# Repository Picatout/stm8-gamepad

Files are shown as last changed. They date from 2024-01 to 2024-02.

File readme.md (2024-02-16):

# stm8 gamepad

Console jeu rétro réalisée sur carte NUCLEO-8S207K8. 

## Caractéristiques

* Sortie vidéo composite NTSC 
* Affichage 200x192 pixels noir & blanc.
* pad de 6 boutons croix et boutons A, B.
* Petit haut-parleur pour tonalités et bruit blanc.

## Documentation

[api.md](api.md)

[docs/api.pdf](docs/api.pdf)

## Prototypes

J'ai fabriqué 2 prototypes.  Le premier est réalisé avec un stm8s207k8 et le 2ième avec une carte NUCLEO-8S207K8. Pour ceux qui n'ont pas de programmeurs ST-LINK la 2ième option s'impose.

### Prototype 1

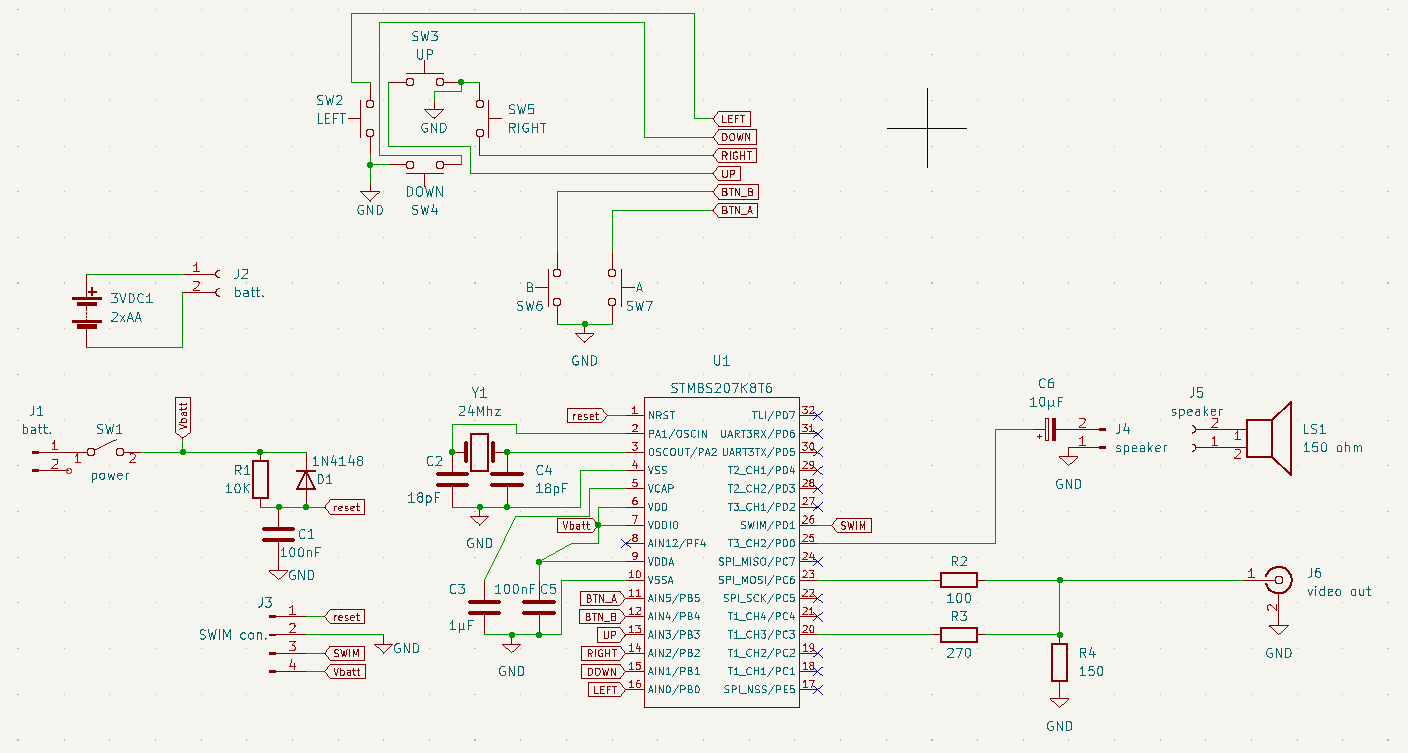
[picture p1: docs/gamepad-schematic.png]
schématique prototype 1


montage prototype 1

L'ensemble tient sur une seule carte.

### Prototype 2

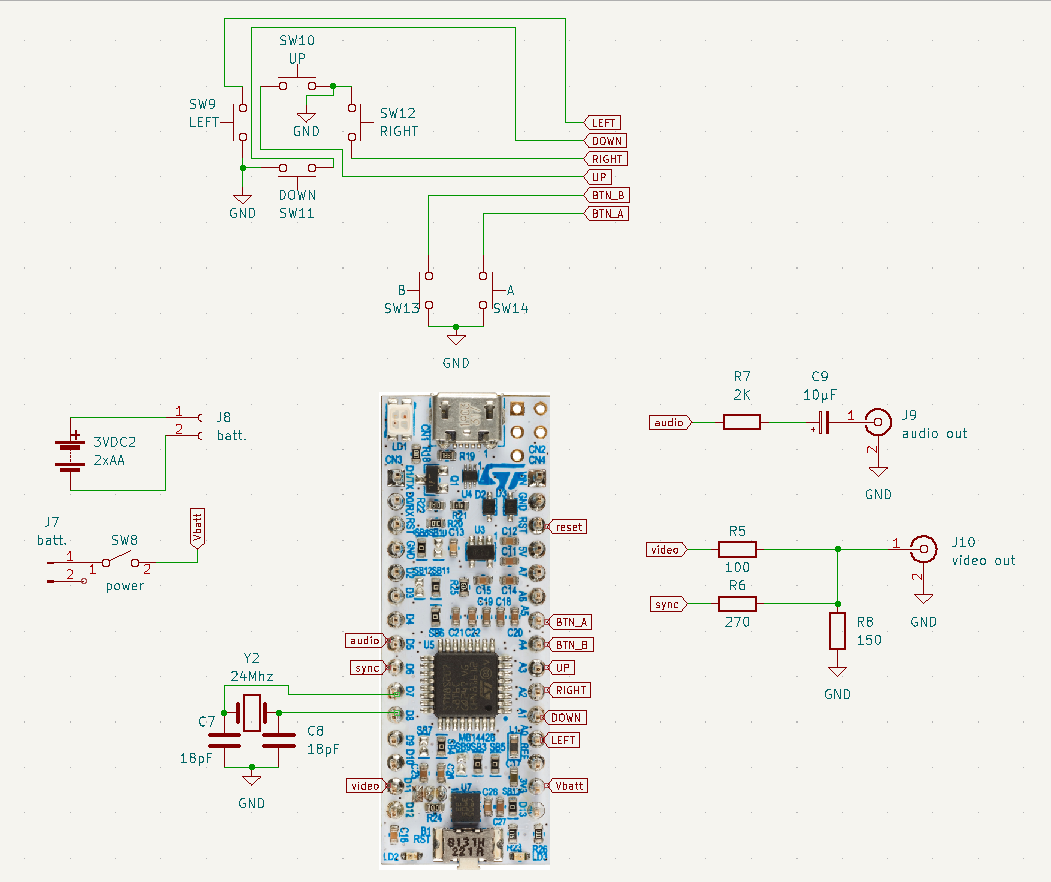
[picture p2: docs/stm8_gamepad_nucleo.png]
schématique prototype 2


montage prototype 2 assemblé

montage prototype 2 désassemblé

La carte des boutons est enfichée par dessus la carte du circuit principal. De plus il n'y a pas de haut-parleur installé mais plutôt une sortie phono RCA (blanc) pour l'audio.

## Mise à jours

### 2024-02-16, V1.5R0

J'ai effectué 2 modficications au circuit ainsi que les modifications logicielles requises par ces changements.

1. La résistance de **150 ohm** à la sortie vidéo a été remplacée par une résistance de **100 ohm** pour augmenter la luminosité.
1. Le cristal de **16Mhz** a été remplacé par un cristal de **24Mhz**. Ceci a 3 conséquences.
    * le rapport largeur/hauteur de l'image qui étirait les pixels en largeur est maintenant très proche ce l'unité donc la routine **circle** n'a plus besoin de faire une correction et le bitmap du chien qui s'affiche au démarrage a un aspect plus normal.
    * l'image n'occupe plus que les 2/3 de la largeur de l'écran. Ça implique que du temps est libéré (environ 17µSec/scan line) donnant plus temps d'exécution au cpu pour les autres tâche.
    * La vitesse d'exécution est augmenter.

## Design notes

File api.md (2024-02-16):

<!--
;;
; Copyright Jacques Deschênes 2023,2024  
; This file is part of stm8-gamepad
;
;     stm8-gamepadis free software: you can redistribute it and/or modify
;     it under the terms of the GNU General Public License as published by
;     the Free Software Foundation, either version 3 of the License, or
;     (at your option) any later version.
;
;     stm8-gamepadis distributed in the hope that it will be useful,
;     but WITHOUT ANY WARRANTY; without even the implied warranty of
;     MERCHANTABILITY or FITNESS FOR A PARTICULAR PURPOSE.  See the
;     GNU General Public License for more details.
;
;     You should have received a copy of the GNU General Public License
;     along with ntsc_tuto.  If not, see <http://www.gnu.org/licenses/>.
;;
-->
# interface d'application 

Ce document décrit les fonctions à utiliser pour programmer des applications pour la console STM8-GAMEPAD.

Les applications doivent-être écrites en assembleur car les paramètres des fonctions sont passés dans les registres **A**,**X** et **Y**  et non sur la pile comme le langage **C** le fait.

Il y a toujours moyen d'écrire les applications en **C** mais en utilisant l'assembleur inline pour charger les registres et faire l'appel vers la sous-routine.

## NOTES 

1. Les valeurs d'intervalles sont indiqué de la façon suivante **[début..fin[ | ]**  
    * Si la valeur *fin* est suivie de **[** ça signifie que cette valeur est exclue de l'intervalle.
    * Si la valeur *fin* est suivie de **]** ça signifie que cette valeur est incluse dans l'intervalle.

2.  **HRES**  Résolution horizontale de l'affichage. 

3.  **VRES** Résolution verticale de l'affichage. 

4. **cx** varible octet contenant la coordonnée x du curseur texte. **[0..CHAR_PER_LINE[**.

5. **cy** variable octet contenant la coordonnée y du curseur texte. **[0..LINE_PER_SCREEN[**.

6. **CHAR_PER_LINE** Nombre de caractères affichable par ligne. 

7. **LINE_PER_SCREEN** Nombre de lignes par écran. 

8. Les variables **cx** et **cy** peuvent-être modifiées par le programme pour positionner le curseur texte. La fonction **tv_cls** les initialisent à **0**.

9. L'espace réservé pour les variables d'application est dans l'intervalle **[4..KERNEL_VAR_ORG[**. Présentement **KERNEL_VAR_ORG=0x60**. Vérifiez cette valeur dans le fichier [hardware_init.asm](hardware_init.asm).  
Les applications définissent leur variables dans le segment **G_DATA** comme suit
```
    .area G_DATA (ABS)
    .org 4 
score: .blkw 1 ; game score 
speed: .blkb 1 ; snake speed delay
chrono: .blkb 1 ; chronometer delay 
max_score: .blkw 1 ; maximum score 
game_flags: .blkb 1 ; game boolean flags 
snake_len: .blkb 1 ; snake length 
snake_dir: .blkb 1 ; head direction 
food_coord: .blkw 1 ; food coordinates
snake_body: .blkw 32 ;  snake rings coords 
```

10. Lorsqu'une application est ajoutée au système ses nom et adresse doivent-être ajoutés au système de menu dans le fichier [app.asm](app.asm). Cette liste doit se terminée par une valeur nulle.
```
prog_list: ; liste des applications disponibles.
.asciz "SNAKE" ; nom qui apparaît dans le menu
.word snake ; nom de la fonction qui lance l'application.
; 2ième application 
.asciz "FALL" 
.word fall
; 3ième application
.asciz "QUICK BROWN FOX"  
.word quick
; fin de la liste
.word 0  
```
Le menu supporte un maximum de 24 applications. C'est le nombre de lignes texte de l'affichage et cette valeur ne devrait pas varier.

11. La mémoire étendue du stm8s207k8 de **32Ko** **[0x10000..0x17FFF]** n'est pas utilisée par le système mais une application peut l'utiliser pour sauvegarder des données persistantes. l'EEPROM de **2Ko** **[0x4000..0x47FF]** peut aussi être utilisée à cet effet.

<hr>

## <a id="index">index</a>

* <a href="#son">SON</a>
* <a href="#keypad">KEYPAD</a>
* <a href="#affichage">AFFICHAGE</a>
* <a href="#divers">DIVERS</a>

##  <a id="son">SON</a> 

* **beep** Cette sous-routine n'accepte aucun paramètre. Elle génère un son de 1000 Hertz pour une durée de 8/60ième de seconde (i.e. ~133msec).
<hr>

* **tone** génère une tonalité de fréquence spécifiée dans le registre **X** et de durée en 60ième de seconde spécifiée dans le registre **A**.
    * **A**   durée du son en 60ìème de seconde. 
    * **X**   fréquence en hertz.
<hr>

* **tune**  Joue une séquence de notes. Le registre **Y** indique l'adresse de la séquence. 
    * **Y**  adresse de la mélodie. Il s'agit d'une liste formée de la fréquence suivit de la durée. La liste doit se terminer par {0,0}. La macro **_note f,d** facilite la constuction de cette liste. 
    * une fréquence nulle indique une pause.

```
	.macro _note  f,d 
	.word f 
	.byte d 
	.endm 

play_scale: 
    ldw y,#gamme 
    call tune 
    ret 

gamme: 
    _note 523,10  ; do 
    _note 554,10  ; do#
    _note 587,10  ; ré 
    _note 622,10  ; ré#
    _note 659,10  ; mi 
    _note 698,10  ; fa 
    _note 740,10  ; fa# 
    _note 784,10  ; sol
    _note 831,10  ; sol#
    _note 880,10  ; la 
    _note 932,10  ; la# 
    _note 988,10  ; si 
    _note 0,0     ; end  
```
<hr>

* **noise**  Produit un bruit blanc d'une durée indiquée par le paramètre passé dans **A**.
    * **A** Durée en 60ième de seconde.

<a href="#index">index</a>

##  <a id="keypad">KEYPAD</a> 

* **keypad_input**  Retourne l'état des 6 boutons dans le registre **A**. Cette lecture n'est pas filtrée pour les rebonds des commutateurs. Les constantes suivantes sont définies pour identifier les boutons.
    * **BTN_LEFT=1**
    * **BTN_DOWN=2**
    * **BTN_RIGHT=4**
    * **BTN_UP=8** 
    * **BTN_B=16**
    * **BTN_A=32**

<hr>

* **read_keypad** Lecture du keypad avec filtrage antirebond. L'état des boutons est retournée dans le registre **A**. Exemple d'utilisation:
```
;--------------------------
; read keypad 
; LEFT turn left 
; RIGHT turn right 
; UP increase speed 
; DOWN decreas speed 
;--------------------------
    KPAD=1
user_input:
    push #0 
    call read_keypad
    jreq 8$ 
    ld (KPAD,sp),a  
    ld a,#BTN_LEFT 
    and a,(KPAD,sp)
    jreq 2$ 
    call rotate_head
    jra 6$
2$: ld a,#BTN_RIGHT 
    and a,(KPAD,sp)
    jreq 3$ 
    call rotate_head
    jra 6$ 
3$:
    ld a,#BTN_UP 
    and a,(KPAD,sp)
    jreq 4$
    ld a,#MIN_SPEED 
    cp a,speed 
    jreq 6$  
    _decz speed
    call prt_info 
    jra 6$ 
4$: ld a,#BTN_DOWN 
    and a,(KPAD,sp)
    jreq 6$
    ld a,#MAX_SPEED 
    cp a,speed 
    jreq 6$
    _incz speed
    call prt_info  
6$:
    ldw x,#10
    call wait_key_release
8$:
    _drop 1 
    ret 
```
<hr>

* **wait_key** Attend qu'un bouton soit enfoncé et retourne l'état dans le registre **A**. 
<hr>

* **wait _key_release** Attend que tous les boutons soient relâchés.  Un délais d'expiration de l'attente doit-être founis dans **X**.
    * **X**  délais d'expiration de l'attente en 60ième de seconde.

<a href="#index">index</a>

##  <a id="affichage">AFFICHAGE</a> 

* **tv_cls**  Efface l'affichage au complet.
<hr>

* **get_pixel** retourne l'état du pixel dans le registre **A**.
    * **XL** coordonnée X du pixel [0..HRES[.
    * **XH** coordonnée Y du pixel [0..VRES[. 

<hr>

* **put_pixel** met le pixel dans l'état déterminé par le contenu du registre **A**
    * **A**  **0** -&gt; éteint le pixel. Autre allume le pixel.
    * **XL** coordonnée X du pixel [0..HRES[.
    * **XH** coordonnée Y du pixel [0..VRES[. 

<hr>

* **set_pixel** Allume un pixel. Les paramètres sont passés dans le registre **X**.
    * **XL** coordonnée X du pixel [0..HRES[.
    * **XH** coordonnée Y du pixel [0..VRES[. 
<hr>

* **reset_pixel** Éteint un pixel. Les paramètres sont passés dans le registre **X**.
    * **XL** coordonnée X du pixel {0..HRES-1}.
    * **XH** coordonnée Y du pixel {0..VRES-1}.
<hr>

* **invert_pixel** Inverse l'état du pixel. Les paramètres sont passés dans le registre **X**.
    * **XL** coordonnée X du pixel {0..HRES-1}.
    * **XH** coordonnée Y du pixel {0..VRES-1}.
<hr>

* **clr_text_line** Efface une ligne de texte.
    * **A**  numéro de la ligne à effacer {0..23}.

<hr>

* **scroll_text_up**  Décale l'affichage texte vers le haut d'une ligne et efface la dernière ligne.
<hr>

* **crlf**  Carriage return line feed. Renvoie le curseur texte au début de la ligne suivante.
<hr>

* **cursor_right** Déplace le curseur texte vers la droite d'un caractère.
<hr>

* **tv_putc** Affiche le caractère qui est dans le registre **A** à la position 
courante du curseur texte. Avance le curseur à la position suivante.
    * **A**  caractère à affiché.
<hr>

* **tv_puts** Affiche une chaîne ce caractères ASCII zéro terminée à la position actuelle du curseur. Àprès l'impression **Y** pointe sur le zéro terminal de la chaîne.
    * **Y** adresse de la chaîne ASCIZ. 
<hr>

* **center_align**  affiche une ligne de texte centrée horizontalement. Àprès l'impression **Y** pointe sur le zéro terminal de la chaîne. 
    * **Y** adresse de la chaîne ASCIZ.

<hr>

* **put_uint16**  Affiche à la position du curseur la valeur entière non signée contenue dans le registre **X**.
    * **X** Entier à afficher.
<hr>

* **roll_up** déroule l'affichage vers le haut jusqu'à ce qu'il soit vide ou qu'une touche du kpad soit enfoncée.
    * **A**  délais contrôlant la vitesse de déroulement. Le délais est en 60ième de secondes.

<hr>

* **line**  Trace une ligne droite entre les coordonnées **{x0,y0}** et **{x1,y1}** excluant ce dernier point.
    * **XL** coordonnée **x0** [0..HRES[
    * **XH** coordonnée **y0** [0..VRES[
    * **YL** coordonnée **x1**  [0..HRES[
    * **YH** coordonnée **y1** [0..VRES[
<hr>

* **rectangle** Dessine un rectangle dont les coordonnées des coins supérieur gauche et inférieur droit sont données.
    * **X**  coordonnées coin supérieur gauche,
        * **XH**  ycoord y0 [0..VRES[   
        * **XL**  xcoord x0 [0..HRES[
    * **Y** coordonnées coin inférieur droit,    
        * **YH**  ycoord y1 [0..VRES[ 
        * **YL**  xcoord x1 [0..HRES[

<hr>

* **circle**  Dessine un cercle avec correction *ASPECT_RATIO* 
    * **A**   rayon 
    * **XL**  xcoord 
    * **XH**  ycooord 

Les constantes pour corriger l'*ASPTECT RATIO* sont dans le fichier [config.inc](config.inc)

* **ASPECT_MUL=59**
* **ASPECT_DIV=36** 

Ces valeurs peuvent dépendre du moniteur utilisé.

<hr>

* **put_sprite** Affiche un petit graphique d'au maximum 8 pixels en largeur et un maximum de **VRES** pixels en hauteur. Chaque rangé du sprite est représenté par un seul octet et le sprite comprend autant d'octets que sa hauteur. La fonction logique **XOR** est utilisée pour afficher les sprites. Cette méthode permet de détecter automatiquement les collisions. La fonction retourne une valeur dand **A** et ajuste le drapeau **Z** en fonction de cette valeur.

Entrées:
* **A** hauteur du sprite 
* **XL** coordonnée x à gauche du sprite.
* **XH** coordonnnée y haut du sprite.
* **Y**  adresse du sprite 

Sorties:
* **A**  différent de zéro s'il y a eu collision 
* **Z**  **0** s'il y a eu collision.
<hr>

* **scroll_up**  Glisse les rangées de l'intervalle [de...jusqu'à[ vers le haut d'une rangée et efface les pixels de la dernière rangée.
    * **XL** *de* 
    * **XH** *jusqu'à* (exclue) 
<hr>

* **scroll_down** Glisse les rangées de l'intervalle [de...jusqu'à[ vers le bas d'une rangée et efface les pixels de la première rangée.
    * **XL** *de* 
    * **XH** *jusqu'à* (exclue)
<hr>

* **scroll_left** Glisse vers la gauche de 4 pixels l'intervalle de rangées [de...jusqu'à[ et efface les pixels à droite de l'écran.
    * **XL** *de* 
    * **XH** *jusqu'à* (exclue)
<hr>

* **scroll_right** Glisse vers la droite de 4 pixels l'intervalle de rangées [de...jusqu'à[ et efface les pixels à gauche de l'écran.
    * **XL** *de* 
    * **XH** *jusqu'à* (exclue)
<hr>

<a href="#index">index</a>

## <a id="divers">DIVERS</a>

* **pause**   Suspend l'exécution pour une durée déterminée par la valeur passée dans **A**.
    * **A** durée de la pause en 60ième de seconde.

<a href="#index">index</a>

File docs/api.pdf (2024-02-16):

api.md | 2024-02-16

# interface d'application

Ce document décrit les fonctions à utiliser pour programmer des applications pour la console STM8-GAMEPAD.

Les applications doivent-être écrites en assembleur car les paramètres des fonctions sont passés dans les registres A,X et Y et non sur la pile comme le langage C le fait.

Il y a toujours moyen d'écrire les applications en C mais en utilisant l'assembleur inline pour charger les registres et faire l'appel vers la sous-routine.

## NOTES

1. Les valeurs d'intervalles sont indiqué de la façon suivante [début..fin[ | ]

Si la valeur fin est suivie de [ ça signifie que cette valeur est exclue de l'intervalle. Si la valeur fin est suivie de ] ça signifie que cette valeur est incluse dans l'intervalle.

2. HRES Résolution horizontale de l'affichage.
3. VRES Résolution verticale de l'affichage.
4. cx varible octet contenant la coordonnée x du curseur texte. [0..CHAR_PER_LINE[.
5. cy variable octet contenant la coordonnée y du curseur texte. [0..LINE_PER_SCREEN[.
6. CHAR_PER_LINE Nombre de caractères affichable par ligne.
7. LINE_PER_SCREEN Nombre de lignes par écran.
8. Les variables cx et cy peuvent-être modifiées par le programme pour positionner le curseur texte. La fonction tv_cls les initialisent à 0.
9. L'espace réservé pour les variables d'application est dans l'intervalle [4..KERNEL_VAR_ORG[. Présentement KERNEL_VAR_ORG=0x60. Vérifiez cette valeur dans le fichier hardware_init.asm. Les applications définissent leur variables dans le segment G_DATA comme suit

.area G_DATA (ABS)
.org 4
score: .blkw 1 ; game score
speed: .blkb 1 ; snake speed delay chrono: .blkb 1 ; chronometer delay max_score: .blkw 1 ; maximum score game_flags: .blkb 1 ; game boolean flags snake_len: .blkb 1 ; snake length snake_dir: .blkb 1 ; head direction food_coord: .blkw 1 ; food coordinates snake_body: .blkw 32 ; snake rings coords

10. Lorsqu'une application est ajoutée au système ses nom et adresse doivent-être ajoutés au système de menu dans le fichier app.asm. Cette liste doit se terminée par une valeur nulle.

prog_list: ; liste des applications disponibles.
.asciz "SNAKE" ; nom qui apparaît dans le menu
.word snake ; nom de la fonction qui lance l'application. ; 2ième application
.asciz "FALL"
.word fall
; 3ième application
.asciz "QUICK BROWN FOX"
.word quick
; fin de la liste
.word 0

Le menu supporte un maximum de 24 applications. C'est le nombre de lignes texte de l'affichage et cette valeur ne devrait pas varier.

11. La mémoire étendue du stm8s207k8 de 32Ko [0x10000..0x17FFF] n'est pas utilisée par le système mais une application peut l'utiliser pour sauvegarder des données persistantes. l'EEPROM de 2Ko [0x4000..0x47FF] peut aussi être utilisée à cet effet.

## index

SON
KEYPAD
AFFICHAGE
DIVERS

## SON

beep Cette sous-routine n'accepte aucun paramètre. Elle génère un son de 1000 Hertz pour une durée de 8/60ième de seconde (i.e. ~133msec).

tone génère une tonalité de fréquence spécifiée dans le registre X et de durée en 60ième de seconde spécifiée dans le registre A.
A durée du son en 60ìème de seconde.
X fréquence en hertz.

tune Joue une séquence de notes. Le registre Y indique l'adresse de la séquence.
Y adresse de la mélodie. Il s'agit d'une liste formée de la fréquence suivit de la durée. La liste doit se terminer par {0,0}. La macro _note f,d facilite la constuction de cette liste.

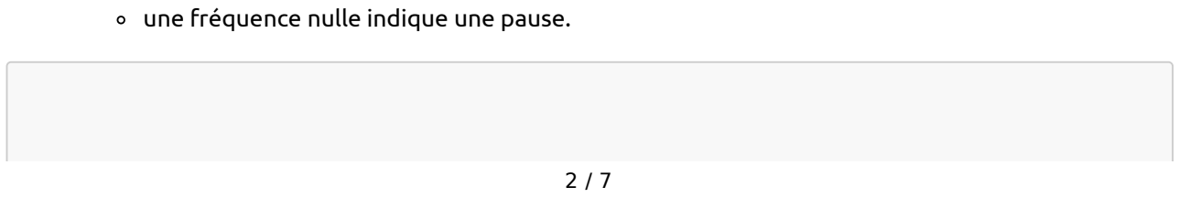
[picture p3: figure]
une fréquence nulle indique une pause.

.macro _note f,d
.word f
.byte d
.endm

play_scale:
ldw y,#gamme
call tune
ret

gamme:
_note 523,10 ; do
_note 554,10 ; do#
_note 587,10 ; ré
_note 622,10 ; ré#
_note 659,10 ; mi
_note 698,10 ; fa
_note 740,10 ; fa#
_note 784,10 ; sol
_note 831,10 ; sol#
_note 880,10 ; la
_note 932,10 ; la#
_note 988,10 ; si
_note 0,0 ; end

noise Produit un bruit blanc d'une durée indiquée par le paramètre passé dans A. A Durée en 60ième de seconde.

index

## KEYPAD

keypad_input Retourne l'état des 6 boutons dans le registre A. Cette lecture n'est pas filtrée pour les rebonds des commutateurs. Les constantes suivantes sont définies pour identifier les boutons. BTN_LEFT=1
BTN_DOWN=2
BTN_RIGHT=4
BTN_UP=8
BTN_B=16
BTN_A=32

read_keypad Lecture du keypad avec filtrage antirebond. L'état des boutons est retournée dans le

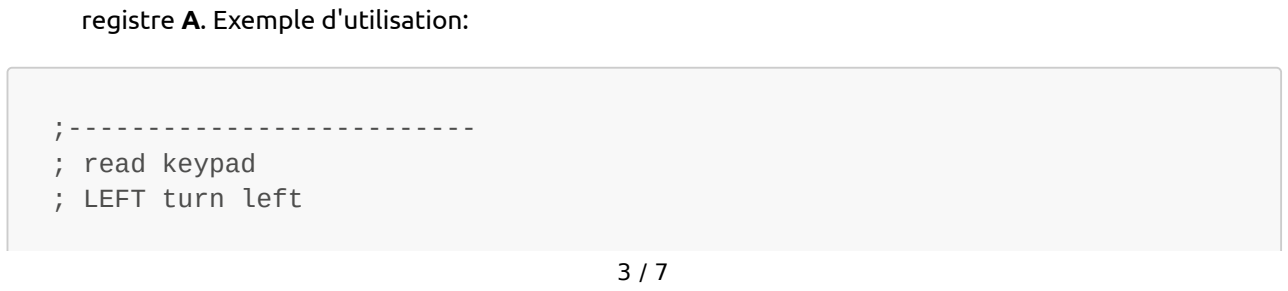
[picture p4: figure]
registre A. Exemple d'utilisation:; ;-------------------------- ; read keypad ; LEFT turn left

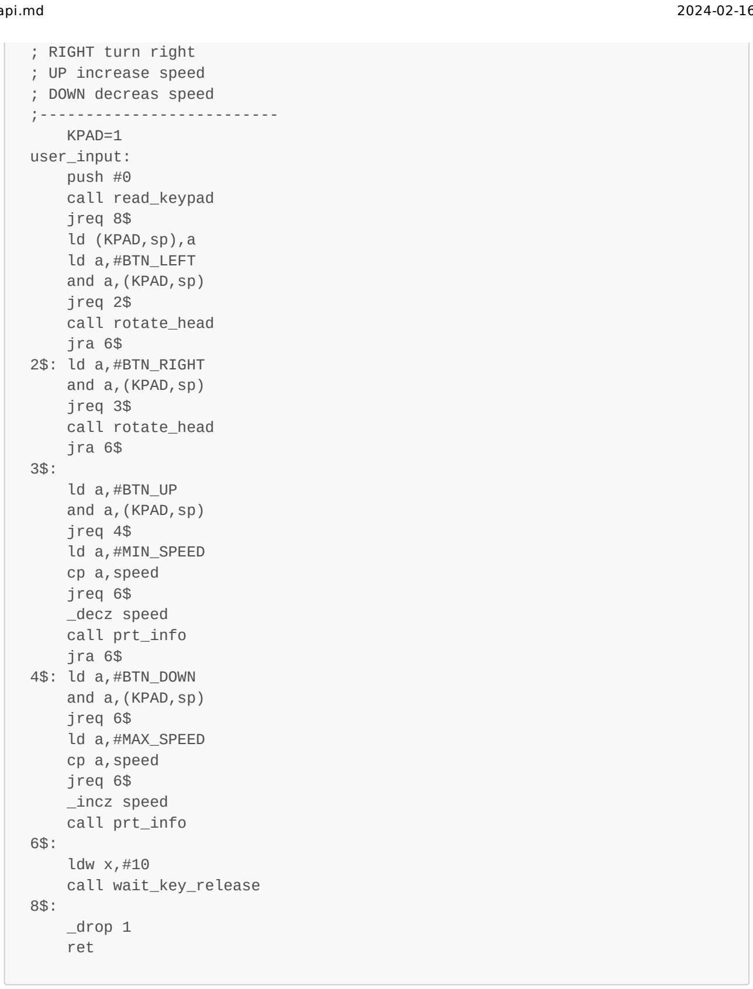
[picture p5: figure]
; RIGHT turn right ; UP increase speed ; DOWN decreas speed ;-------------------------- KPAD=1 user_input: push #0 call read_keypad jreq 8$ ld (KPAD,sp),a ld a,#BTN_LEFT and a,(KPAD,sp) jreq 2$ call rotate_head jra 6$ 2$: ld a,#BTN_RIGHT and a,(KPAD,sp) jreq 3$ call rotate_head jra 6$; ld a,#BTN_UP and a,(KPAD,sp) jreq 4$ ld a,#MIN_SPEED cp a,speed jreq 6$ _decz speed call prt_info jra 6$ 4$: ld a,#BTN_DOWN and a,(KPAD,sp) jreq 6$ ld a,#MAX_SPEED cp a,speed jreq 6$ _incz speed call prt_info; ldw x,#10 call wait_key_release; _drop 1 ret

wait_key Attend qu'un bouton soit enfoncé et retourne l'état dans le registre A.

wait _key_release Attend que tous les boutons soient relâchés. Un délais d'expiration de l'attente doit-être founis dans X.
X délais d'expiration de l'attente en 60ième de seconde.

index

## AFFICHAGE

tv_cls Efface l'affichage au complet.

get_pixel retourne l'état du pixel dans le registre A. XL coordonnée X du pixel [0..HRES[.
XH coordonnée Y du pixel [0..VRES[.

put_pixel met le pixel dans l'état déterminé par le contenu du registre A A 0 -> éteint le pixel. Autre allume le pixel.
XL coordonnée X du pixel [0..HRES[.
XH coordonnée Y du pixel [0..VRES[.

set_pixel Allume un pixel. Les paramètres sont passés dans le registre X. XL coordonnée X du pixel [0..HRES[.
XH coordonnée Y du pixel [0..VRES[.

reset_pixel Éteint un pixel. Les paramètres sont passés dans le registre X. XL coordonnée X du pixel {0..HRES-1}.
XH coordonnée Y du pixel {0..VRES-1}.

invert_pixel Inverse l'état du pixel. Les paramètres sont passés dans le registre X. XL coordonnée X du pixel {0..HRES-1}.
XH coordonnée Y du pixel {0..VRES-1}.

clr_text_line Efface une ligne de texte.
A numéro de la ligne à effacer {0..23}.

scroll_text_up Décale l'affichage texte vers le haut d'une ligne et efface la dernière ligne.

crlf Carriage return line feed. Renvoie le curseur texte au début de la ligne suivante.

cursor_right Déplace le curseur texte vers la droite d'un caractère.

tv_putc Affiche le caractère qui est dans le registre A à la position courante du curseur texte. Avance le curseur à la position suivante.
A caractère à affiché.

tv_puts Affiche une chaîne ce caractères ASCII zéro terminée à la position actuelle du curseur. Àprès l'impression Y pointe sur le zéro terminal de la chaîne.

Y adresse de la chaîne ASCIZ.

center_align affiche une ligne de texte centrée horizontalement. Àprès l'impression Y pointe sur le zéro terminal de la chaîne.
Y adresse de la chaîne ASCIZ.

put_uint16 Affiche à la position du curseur la valeur entière non signée contenue dans le registre X. X Entier à afficher.

roll_up déroule l'affichage vers le haut jusqu'à ce qu'il soit vide ou qu'une touche du kpad soit enfoncée.
A délais contrôlant la vitesse de déroulement. Le délais est en 60ième de secondes.

line Trace une ligne droite entre les coordonnées {x0,y0} et {x1,y1} excluant ce dernier point. XL coordonnée x0 [0..HRES[
XH coordonnée y0 [0..VRES[
YL coordonnée x1 [0..HRES[
YH coordonnée y1 [0..VRES[

rectangle Dessine un rectangle dont les coordonnées des coins supérieur gauche et inférieur droit sont données.
X coordonnées coin supérieur gauche,
XH ycoord y0 [0..VRES[
XL xcoord x0 [0..HRES[
Y coordonnées coin inférieur droit, YH ycoord y1 [0..VRES[
YL xcoord x1 [0..HRES[

circle Dessine un cercle avec correction ASPECT_RATIO A rayon
XL xcoord
XH ycooord

Les constantes pour corriger l'ASPTECT RATIO sont dans le fichier config.inc

ASPECT_MUL=59
ASPECT_DIV=36

Ces valeurs peuvent dépendre du moniteur utilisé.

put_sprite Affiche un petit graphique d'au maximum 8 pixels en largeur et un maximum de VRES pixels en hauteur. Chaque rangé du sprite est représenté par un seul octet et le sprite comprend autant d'octets que sa hauteur. La fonction logique XOR est utilisée pour afficher les sprites. Cette méthode permet de détecter automatiquement les collisions. La fonction retourne une valeur dand A et ajuste le drapeau Z en fonction de cette valeur.

Entrées:

A hauteur du sprite
XL coordonnée x à gauche du sprite. XH coordonnnée y haut du sprite. Y adresse du sprite

Sorties:

A différent de zéro s'il y a eu collision
Z 0 s'il y a eu collision.

scroll_up Glisse les rangées de l'intervalle [de...jusqu'à[ vers le haut d'une rangée et efface les pixels de la dernière rangée.
XL de
XH jusqu'à (exclue)

scroll_down Glisse les rangées de l'intervalle [de...jusqu'à[ vers le bas d'une rangée et efface les pixels de la première rangée.
XL de
XH jusqu'à (exclue)

scroll_left Glisse vers la gauche de 4 pixels l'intervalle de rangées [de...jusqu'à[ et efface les pixels à droite de l'écran.
XL de
XH jusqu'à (exclue)

scroll_right Glisse vers la droite de 4 pixels l'intervalle de rangées [de...jusqu'à[ et efface les pixels à gauche de l'écran.
XL de
XH jusqu'à (exclue)

index

## DIVERS

pause Suspend l'exécution pour une durée déterminée par la valeur passée dans A. A durée de la pause en 60ième de seconde.

index

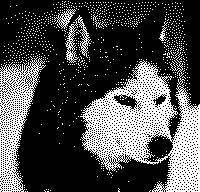
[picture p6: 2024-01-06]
docs/loup_200x192px_bw.bmp

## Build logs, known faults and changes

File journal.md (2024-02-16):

### 2024-02-15

* Modfication matérielle, remplacé le cristal de 16 Mhz par un cristal de 20Mhz.
* Remplacé résistance de 150 ohm par 100 ohm à la sortie video pour augmenter la brillance.

### 2024-01-28

* Nouveau tag V1.4R0 

* Ajout de la routine graphique *cercle*. 
    * **cercle**  
        * **A**   rayon 
        * **XL**  xcoord 
        * **XH**  ycooord 

### 2024-01-24

* Correction à la routine *rectangle*, le pixel du coin inférieur droit était manquant. V1.3R1.

* Ajout de l'option **RANDOM FILL** au menu de [conway.asm](conway.asm).

* Travail sur [fall.asm](fall.asm) pour ajusté la vitesse: 
    * **fall_dly = INIT_DLY-fall_score/1000**

* Corrigé jeux pour la nouvelle interface de *line* 

* Modifié l'interface de la routine *line*.
* **line**  Trace une ligne droite entre les coordonnées **{x0,y0}** et **{x1,y1}** excluant ce dernier point.
    * **XL** coordonnée **x0** [0..HRES[
    * **XH** coordonnée **y0** [0..VRES[
    * **YL** coordonnée **x1**  [0..HRES[
    * **YH** coordonnée **y1** [0..VRES[

### 2024-01-23

* Modifié l'interface de la routine *rectangle*.
* **rectangle** Dessine un rectangle dont les coordonnées des coins supérieur gauche et inférieur droit sont données.
    * **X**  coordonnées coin supérieur gauche,
        * **XH**  ycoord y0 [0..VRES[   
        * **XL**  xcoord x0 [0..HRES[
    * **Y** coordonnées coin inférieur droit,    
        * **YH**  ycoord y1 [0..VRES[ 
        * **YL**  xcoord x1 [0..HRES[
        
* fall presque complété, reste à ajouté un niveau de difficulté par augmentation de la vitesse en fonction du pointage.

* Modifié routine *tune* dans [sound.asm](sound.asm) pour que la mélodie puisse être interrompue sans délais.

* Modification de la routine kpad_input. Maintenant gérée par une interruption externe. L'état des boutons est enregistré dans la variable *keyin*.
    * Ajout de la variable *keyin*. 

* Ajout d'indicateurs booléens dans la variable *flags* 
    * **F_ST_ABORT**  mis à 1 par la routine *tune* interrompt la mélodie si un bouton du keypad est enfoncé.
    * **F_GT_ABORT**  mis à 1 par une routine interrompt *pause* si un bouton du keypad est enfoncé.

### 2024-01-21

* Trvail sur [fall.asm](fall.asm).

* Corrigé bogue dans routine *again* du fichier [app.asm](app.asm).

### 2024-01-20

* Trvail sur [fall.asm](fall.asm).

* Ajout de la routine *strlen* dans [display.asm](display.asm).

### 2024-01-19 

* Trvail sur [fall.asm](fall.asm) [display.asm](display.asm)
    * **rectangle**   Dessine un rectangle. 
        * **XL**  coordonnée gauche 
        * **XH**  coordonnée haut 
        * **YL**  largeur 
        * **YH**  hauteur 

* Modification de *rectangle* dans 

### 2024-01-18

* Correction mineure à la routine *again* dans le fichier [app.asm](app.asm). Version V1.2R1

### 2024-01-17

* version **V1.2R0**. 

* Jeu Cadena Débogué.

* Ajout de 2 routines dans [display.asm](display.asm)
    * **clr_text_line**  efface une ligne de texte.
        * **A**  contient no. de ligne  à effacé. 

    * **rectangle**   Dessine un rectangle. 
        * **XL**  coordonnée X0 
        * **XH**  coordonnée X1 
        * **YL**  coordonnée Y0 
        * **YH**  coordonnée Y1

* Travail sur jeu [cadena.asm](cadena.asm).

* Modifié routines de lecture du  keypad. 

### 2024-01-16

* Travail sur jeu [cadena.asm](cadena.asm).

### 2024-01-15

* Travail sur jeu [cadena.asm](cadena.asm).

### 2024-01-14 

**A FAIRE**  **eval_try** aglorithme complexe.

* Travail sur jeu [cadena.asm](cadena.asm).

### 2024-01-13

* Travail sur jeu [cadena.asm](cadena.asm).
* Ajout de la routine *again*  dans [app.asm](app.asm).

### 2024-01-12

* Travail sur un nouveau jeu appellé *CADENA*. Il s'agit d'une variante du jeu mastermind. Un nombre aléatoire de 4 chiffres est généré et le joueur doit deviner la combinaison en un nombre minimum de d'essais. 
    * Si 1 ou plusieurs chiffres qu'il a choisi font parti de la combinaison un __*__ apparaît à droite de la rangée.
    * Si 1 ou plusieurs chiffres apparaît en bonne position un **+** apparaît à droite de la rangée.
    * Si aucun chiffre ne fait parti de la combinaison aune indication n'est donnée. 
Le joueur dispose d'un maximum de 12 essais.

### 2024-01-11

* Travail sur [fall.asm](fall.asm).
* Ajouter routines *roll_up* et *scroll_text* dans [display.asm](display.asm).
* Nettoyage de [conway.asm](conway.asm).

### 2024-01-10

* Ajouter d'un menu avec des configurations prédéfinies dans [conway.asm](conway.asm). 
* 11:49  Complété [conway.asm](conway.asm).

### 2024-01-06

* Recommencé à travailler sur [conway.asm](conway.asm).

* Complété travail sur splash screen.

### 2024-01-05

* Travail sur [splash.asm](splash.asm).

* Écrire de l'outils de conversion de bitmaps en fichier asm pour le projet. [bmp_2_asm.c](tools/bmp_2_asm.c).

* Travail sur jeu [conway.asm]

* Déplacer le tampon vidéo *tv_buffer* vers la fin de la mémoire RAM sous la pile pour donné plus de mémoire aux applications. 
* Les variables système sont déplacé à la fin de la page 0.

### 2023-12-29

* Ajout de la sous-routine **tune** dans hardware_init.asm 

* Travail sur snake.asm
    * Ajout chronomètre TIME OUT avec bargraph.
    * Ajuster dimension de l'arène pur que largeur et hauteur soit un multiple de SNAKE__SPRITE_WIDTH et SNAKE_SPRITE_HEIGHT.

### 2023-12-28

* Travail sur snake.asm 
    * Ajout du contrôle de vitesse du serpent avec les touvhe HAUT|BAS.
    * Modification affichage score.
    * Ajout BEEP lorsque le serpent avale la souris.
    * Ajout NOISE quand le serpent meure.

### 2023-12-27

* Éliminer TIMER4 pour les délais utilise à la place l'interruption de TIMER1. La granularité tombe à 1/60 de seconde mais la sortie vidéo est plus propre.

* Augmenté delais pour TIMER4 à 2msec. Supprimé modulo 10 pour game_timer et sound_timer.

### 2023-12-26

* Modification prototype 1 pour que les boutons du keypad sur le même port que pour le prototype 2.

### 2023-12-25

* Fabrication d'un nouveau prototype du gamepad utilisant une carte NUCLEO-8S207K8
* Ajout de tas de merde au jeu snake.asm 
* Ajout feuille dans projet KiCAD pour version NUCLEO-8S207K8.

### 2023-12-24

* Travail sur display.asm 
    * Ajout de scroll_up 
    * Ajout de scroll_down 
    * Ajout de scroll_left 
    * Ajout de scroll_right 
    * Renommé move_up en move_text_up 
    * Ajout des sous-routines move_up et fill dans app.asm 
    
### 2023-12-23

* Travail sur jeu snake.asm 

### 2023-12-22

* Modification du circuit video output.
* Commutation audio_out et BTN_A. Bouton maintenant sur PD3 et audio_out sur PD0 TIM3_CH2.
* Débogué tone. 
* Corrigé draw_wall dans snake.asm

### 2023-12-21

* Assemblage du nouveau circuit et test préliminiaires.

### 2023-12-20

* Création d'un nouveau circuit pour le mcu **STM8S207K8T**. Résolution vidéo augmenté à 200x192 pixels.

### 2023-12-17

* Début travail sur fall.asm 

### 2023-12-15

* Complété mécanique des collisions.
* Ajout message de fin de partie avec pointage et pointage maximum et prompt pour nouvelle partie ou quitter.
* Ajout du menu jeux.

### 2023-12-13

* Travail sur snake.asm.
    * AJout de la nourriture
    * Travail sur les collisions

### 2023-12-12

* Travail sur snake.asm. 
    * Mécanique de déplacement du serpent déboguée.
    * Lecture du keypad déboguée.

### 2023-12-11

* Travail sur snake.asm

### 2023-12-10

* Test keypad complété.
* Modification à tvout.asm
* Retravaillé certains caractères de la police font_6x8.asm

### 2023-12-09

* Modification aux routines *pixel_addr* et *bit_mask* pour élimiter 2 instructions dans *pixel_addr*.
* Réécriture de la routine *tv_putc* pour améliorer la rapidité. Gain de 6x.
* Ajout de la routine *read_keypad*.

### 2023-12-04

* Enlevé monitor.asm du projet
* Ajout de des sous-routines *crlf*,*cursor_right*,*scrollup* et  *put_uint16*.
* Ajout de la routine *put_sprite*

### 2023-12-03

* Complété le circuit en ajoutant le cristal 16Mhz 
* Déboguer tvout.asm 
* Ajout de fonctions dans display.asm
* Ajout xor_prng.asm 
* corrigé bogue dans pixel_addr
* Ajout de font_small_hex.asm

### 2023-12-02

* Démarrage du projet 

* Conception du circuit électronique comprenant:
    * Sortie vidéo NTSC monochrome 96x64 pixels 
    * Un petit haut-parleur pour générer des tonalités
    * Un keypad de 6 touches 
    * Alimentation par 3 piles AAA

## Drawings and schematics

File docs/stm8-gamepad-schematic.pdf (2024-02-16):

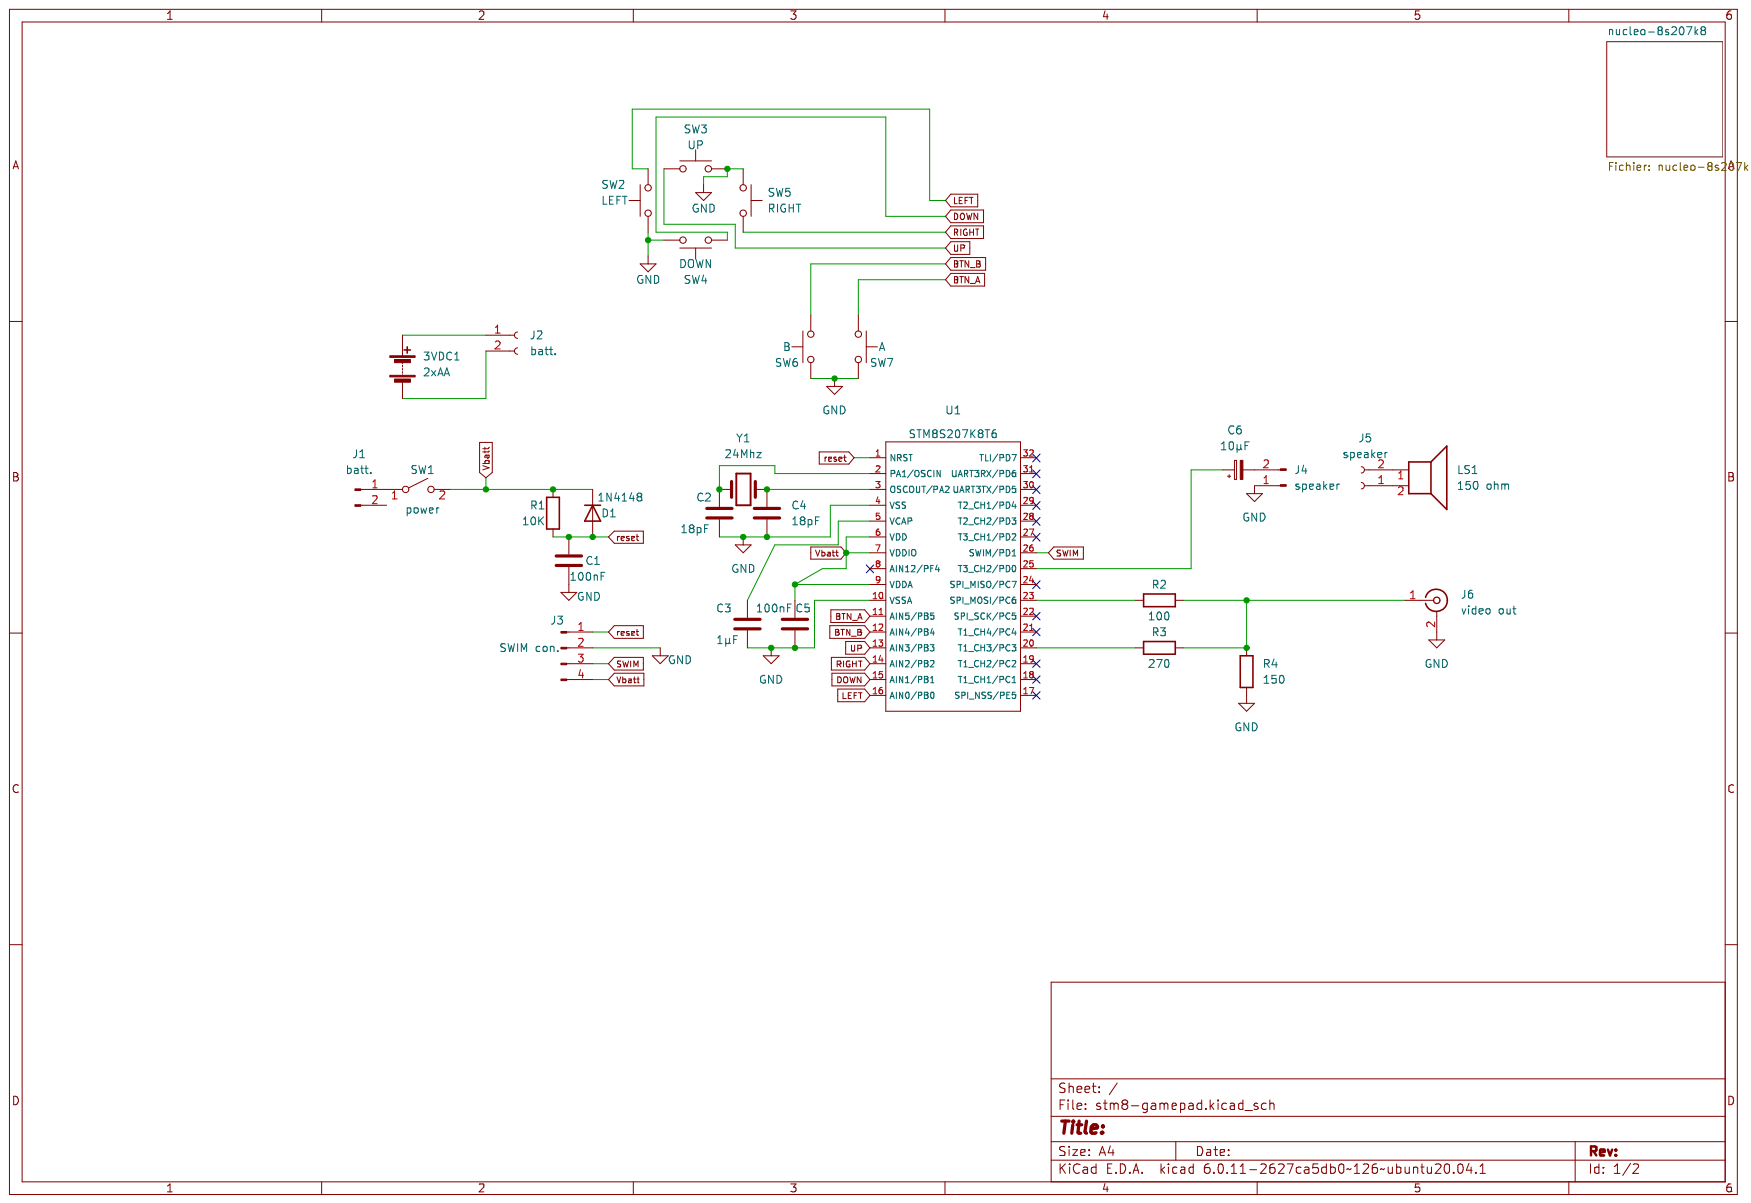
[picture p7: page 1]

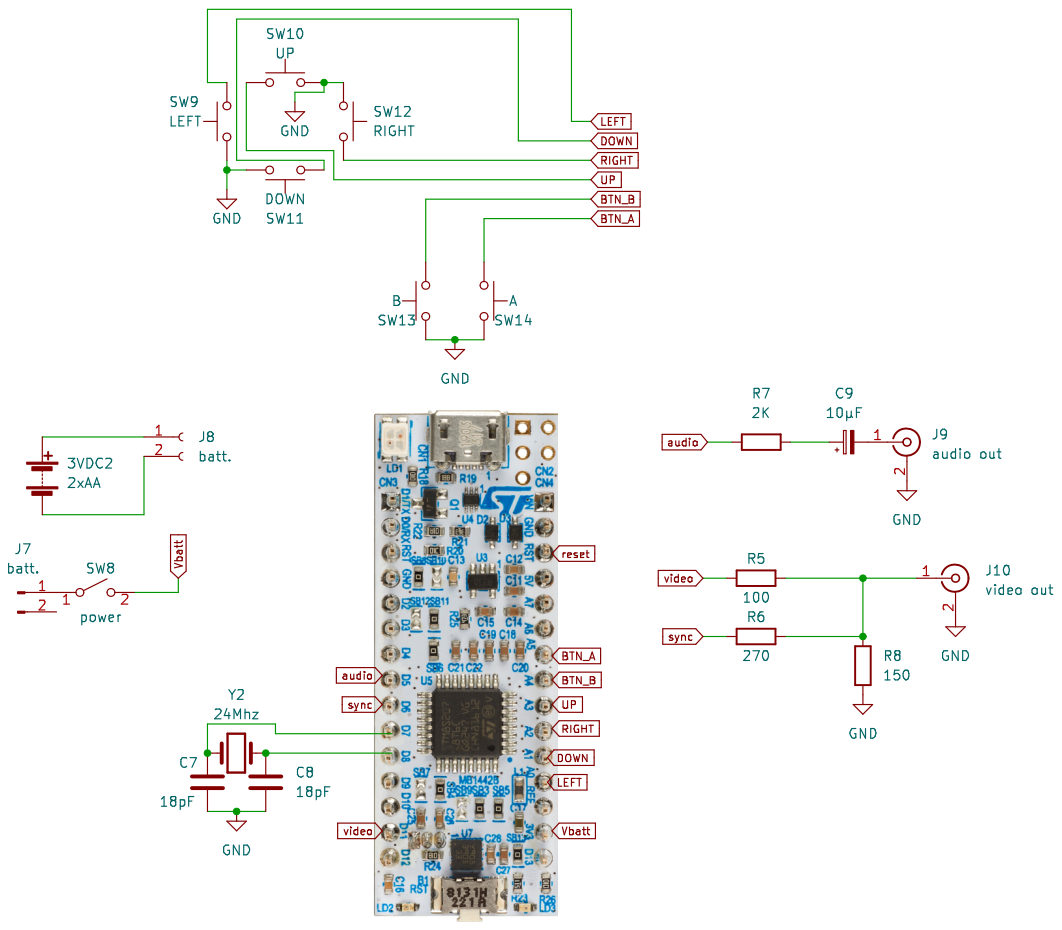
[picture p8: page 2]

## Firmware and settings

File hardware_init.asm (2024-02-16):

;;
; Copyright Jacques Deschênes 2023,2024  
; This file is part of stm8-gamepad
;
;     stm8-gamepad is free software: you can redistribute it and/or modify
;     it under the terms of the GNU General Public License as published by
;     the Free Software Foundation, either version 3 of the License, or
;     (at your option) any later version.
;
;     stm8-gamepad is distributed in the hope that it will be useful,
;     but WITHOUT ANY WARRANTY; without even the implied warranty of
;     MERCHANTABILITY or FITNESS FOR A PARTICULAR PURPOSE.  See the
;     GNU General Public License for more details.
;
;     You should have received a copy of the GNU General Public License
;     along with ntsc_tuto.  If not, see <http://www.gnu.org/licenses/>.
;;


;;;;;;;;;;;;;;;;;;;;;;;;;;;;;;;
;;; hardware initialization
;;;;;;;;;;;;;;;;;;;;;;;;;;;;;; 

;------------------------
; if unified compilation 
; must be first in list 
;-----------------------

    .module HW_INIT 

    .include "config.inc"

STACK_EMPTY=RAM_SIZE-1 
STACK_SIZE=128   
;;-----------------------------------
    .area SSEG (ABS)
;; working buffers and stack at end of RAM. 	
;;-----------------------------------
; video buffe
VBUFF_SIZE=HRES*VRES/8 ; 200*192/8=4800 bytes 
    .org RAM_SIZE-STACK_SIZE-VBUFF_SIZE
tv_buffer: .blkb  VBUFF_SIZE
; stack at end of RAM 
stack_full:: .ds STACK_SIZE   ; control stack full 
stack_unf: ; stack underflow ; RAM end +1 -> 0x1800

;;--------------------------------------
    .area HOME 
;; interrupt vector table at 0x8000
;;--------------------------------------

    int cold_start			; RESET vector 
	int NonHandledInterrupt ; trap instruction 
	int NonHandledInterrupt ;int0 TLI   external top level interrupt
	int NonHandledInterrupt ;int1 AWU   auto wake up from halt
	int NonHandledInterrupt ;int2 CLK   clock controller
	int NonHandledInterrupt ;int3 EXTI0 gpio A external interrupts
	int KeypadIntHandler    ;int4 EXTI1 gpio B external interrupts
	int NonHandledInterrupt ;int5 EXTI2 gpio C external interrupts
	int NonHandledInterrupt ;int6 EXTI3 gpio D external interrupts
	int NonHandledInterrupt ;int7 EXTI4 gpio E external interrupts
	int NonHandledInterrupt ;int8 beCAN RX interrupt
	int NonHandledInterrupt ;int9 beCAN TX/ER/SC interrupt
	int NonHandledInterrupt ;int10 SPI End of transfer
	int ntsc_sync_interrupt ;int11 TIM1 update/overflow/underflow/trigger/break
	int ntsc_video_interrupt ; int12 TIM1 capture/compare
	int NonHandledInterrupt ;int13 TIM2 update /overflow
	int NonHandledInterrupt ;int14 TIM2 capture/compare
	int NonHandledInterrupt ;int15 TIM3 Update/overflow
	int NonHandledInterrupt ;int16 TIM3 Capture/compare
	int NonHandledInterrupt ;int17 UART1 TX completed
	int NonHandledInterrupt ;int18 UART1 RX full  
	int NonHandledInterrupt ;int19 I2C 
	int NonHandledInterrupt ;int20 UART3 TX completed
.if HAS_UART 
	int UartRxHandler       ; int21 UART3 RX full 
.else 
	int NonHandledInterrupt ;int21 UART3 RX full
.endif ;; HAS_UART
	int NonHandledInterrupt ;int22 ADC2 end of conversion
	int NonHandledInterrupt ;int23 TIM4 update$overflow 
	int NonHandledInterrupt ;int24 flash writing EOP/WR_PG_DIS
	int NonHandledInterrupt ;int25  not used
	int NonHandledInterrupt ;int26  not used
	int NonHandledInterrupt ;int27  not used
	int NonHandledInterrupt ;int28  not used
	int NonHandledInterrupt ;int29  not used


SYS_VAR_SIZE=32 
KERNEL_VAR_ORG=256-SYS_VAR_SIZE 
;--------------------------------------
    .area DATA (ABS)
	.org KERNEL_VAR_ORG 
;--------------------------------------	

ticks: .blkw 1 ; 2 millisecond counter
delay_timer: .blkb 1 
sound_timer: .blkb 1 
; keep the following 3 variables in this order 
acc16:: .blkb 1 ; 16 bits accumulator, acc24 high-byte
acc8::  .blkb 1 ;  8 bits accumulator, acc24 low-byte  
fmstr:: .blkw 1 ; frequency in Mhz of Fmaster
ptr16::  .blkb 1 ; 16 bits pointer , farptr high-byte 
ptr8:   .blkb 1 ; 8 bits pointer, farptr low-byte  
flags:: .blkb 1 ; various boolean flags
seedx: .blkw 1  ; prng seed bits 0..15
seedy: .blkw 1  ; prng seed bits 16..31

; tvout variables 
ntsc_flags: .blkb 1 
ntsc_phase: .blkb 1 ; 
scan_line: .blkw 1 ; video lines {0..262} 

; display variables 
cy: .blkb 1 ; text cursor y coord {0..7} 
cx: .blkb 1 ; text cursor y coord {0..15}

; keypad variables 
keyin: .blkb 1 ; keypad value read within KeypadIntHandler 

.if HAS_UART 
RX_QUEUE_SIZE=8 
rx1_head: .blkb 1 
rx1_tail: .blkb 1 
rx1_queue: .blkb 8 
.endif ;; HAS_UART 

	.area CODE 

;;;;;;;;;;;;;;;;;;;;;;;;;;;;
; non handled interrupt 
; reset MCU
;;;;;;;;;;;;;;;;;;;;;;;;;;;
NonHandledInterrupt:
	_swreset ; see "inc/gen_macros.inc"


;------------------------------
; EXTI1 interrupt handler 
; respond to GPIOB keypad input 
; on both edge 
;------------------------------ 
KeypadIntHandler:
	ld a,KPAD_IDR 
	and a,#BTN_MASK 
	xor a,#BTN_MASK  
	_straz keyin
	btjf flags,#F_ST_ABORT,1$ 
	bres flags,#F_SOUND_TMR
	bres flags,#F_ST_ABORT 
1$: btjf flags,#F_GT_ABORT,2$ 
	bres flags,#F_GAME_TMR
	bres flags,#F_GT_ABORT
2$:
	iret  

;;;;;;;;;;;;;;;;;;;;;;;;;;;;;;;;;;;;;;;;;
;    peripherals initialization
;;;;;;;;;;;;;;;;;;;;;;;;;;;;;;;;;;;;;;;;;

;----------------------------
; FMSTR=20Mhz 
; program 1 wait state in OPT7 
;----------------------------
wait_state:
	tnz FLASH_WS ; OPT7  
	jrne opt_done ; already set  
	ld a,#1 
	call unlock_eeprom 
	ld FLASH_WS,a 
	cpl a 
	ld FLASH_WS+1,a 
	btjf FLASH_IAPSR,#FLASH_IAPSR_EOP,.
	btjf FLASH_IAPSR,#FLASH_IAPSR_HVOFF,.
	_swreset 
opt_done:
	ret  

unlock_eeprom:
	btjt FLASH_IAPSR,#FLASH_IAPSR_DUL,9$
	mov FLASH_CR2,#0 
	mov FLASH_NCR2,#0xFF 
	mov FLASH_DUKR,#FLASH_DUKR_KEY1
    mov FLASH_DUKR,#FLASH_DUKR_KEY2
	btjf FLASH_IAPSR,#FLASH_IAPSR_DUL,.
9$:	
    bset FLASH_CR2,#FLASH_CR2_OPT
    bres FLASH_NCR2,#FLASH_CR2_OPT 
	ret

;----------------------------------------
; inialize MCU clock 
; select HSE 
; no CPU divisor 
;----------------------------------------
clock_init:	
	bres CLK_SWCR,#CLK_SWCR_SWIF
	mov CLK_SWR,#CLK_SWR_HSE 
	bset CLK_SWCR,#CLK_SWCR_SWEN
	btjf CLK_SWCR,#CLK_SWCR_SWIF,. 
2$: 
	clr CLK_CKDIVR   	
	ret

;----------------------------------
; TIMER3 used as audio tone output 
; on port D:2. pin 27
; channel 3 configured as PWM mode 1 
;-----------------------------------  
timer3_init:
	bset CLK_PCKENR1,#CLK_PCKENR1_TIM3 ; enable TIMER3 clock 
 	bset SOUND_PORT+GPIO_DDR,#SOUND_BIT
	mov TIM3_CCMR2,#(6<<TIM3_CCMR2_OC2M) ; PWM mode 1 
	mov TIM3_PSCR,#8 ; Ft2clk=fmstr/256=62500 hertz 
	bres TIM3_CR1,#TIM3_CR1_CEN
	bres TIM3_CCER1,#TIM3_CCER1_CC2E
	ret 
 
 ;--------------------
; initialize keypad 
; gpio with EXTI1 
; set on both edge
;--------------------
keypad_init:
	ld a,#(3<<2) ; both edge trigger interrupt 
	or a,EXTI_CR1 
	ld EXTI_CR1,a 
	ld a,KPAD_PORT+GPIO_CR2 
	or a,#BTN_MASK ; enable exti on keypad buttons inputs 
	ld KPAD_PORT+GPIO_CR2,a  
	ret
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

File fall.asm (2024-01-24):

;;
; Copyright Jacques Deschênes 2023,2024  
; This file is part of stm8-gamepad
;
;     stm8-gamepadis free software: you can redistribute it and/or modify
;     it under the terms of the GNU General Public License as published by
;     the Free Software Foundation, either version 3 of the License, or
;     (at your option) any later version.
;
;     stm8-gamepadis distributed in the hope that it will be useful,
;     but WITHOUT ANY WARRANTY; without even the implied warranty of
;     MERCHANTABILITY or FITNESS FOR A PARTICULAR PURPOSE.  See the
;     GNU General Public License for more details.
;
;     You should have received a copy of the GNU General Public License
;     along with ntsc_tuto.  If not, see <http://www.gnu.org/licenses/>.
;;

;-------------------
; FALL 
; TRETIS  variant
;-------------------
; block dimensions
DX=4
DY=6 
BLOCK_WIDTH=4 
BLOCK_HEIGHT=6 

; well dimensions and position 
WELL_WIDTH=BLOCK_WIDTH*10
WELL_HEIGHT=BLOCK_HEIGHT*22
WELL_BOTTOM=VRES-BLOCK_HEIGHT  
WELL_TOP=WELL_BOTTOM-WELL_HEIGHT-1
WELL_LEFT=(HRES-WELL_WIDTH)/2
WELL_RIGHT=WELL_LEFT+WELL_WIDTH+1 
; next tetramino box dimensions and position 
NEXT_WIDTH=4*BLOCK_WIDTH+4
NEXT_HEIGHT=4*BLOCK_HEIGHT+4
NEXT_LEFT=WELL_RIGHT+2 
NEXT_TOP=WELL_TOP 
NEXT_BOTTOM=NEXT_TOP+NEXT_HEIGHT+1 
NEXT_RIGHT=NEXT_LEFT+NEXT_WIDTH+1
NEXT_COORDS=((NEXT_TOP+2)<<8)+NEXT_LEFT+2

INIT_DLY=12 

; score gain as row drop 
ONE_ROW=100
TWO_ROWS=250
THREE_ROWS=450
FOUR_ROWS=800

    .area G_DATA 
    .org 4 

lines_dropped: .blkw 1 ; number of lines dropped
fall_score: .blkw 1 ; score 
cur_tetra: .blkb 1  ; current tetra falling ; {0..6}
next_tetra: .blkb 1 ; next tetra to fall {0..6} 
tetra_rot: .blkb 1 ;tetra rotation {0..3}
tetra_y: .blkb 1 ; current tetra y coord 
tetra_x: .blkb 1 ; current tetra x coord 
top_y:  .blkb 1 ; top tetra y coord 
fall_dly: .blkb 1 ; falling speed delay 

    .area CODE 
; basic sprite 

FALL_GAIN: .word 0,ONE_ROW,TWO_ROWS,THREE_ROWS,FOUR_ROWS 

TBLOCK: .byte 0xF0,0xF0,0xF0,0xF0,0xF0,0xF0


; sprites 
; list of BLOCK with relative coordinate to top left corner.
; last byte is sprite width  

; tetramino building macro  
    .macro _rpos x,y 
    .word (y<<8)+x 
    .endm 

; list of tetraminos in all rotations 
; horizontal I
I0: 
_rpos 0,0 
_rpos DX,0
_rpos 2*DX,0
_rpos 3*DX,0
.byte 4*BLOCK_WIDTH ; tetramino width  
; vertical I 
I1: ; vertical I 
_rpos 0,0 
_rpos 0,DY 
_rpos 0,2*DY 
_rpos 0,3*DY
.byte BLOCK_WIDTH ; width  
; square 
SQR: 
_rpos 0,0 
_rpos DX,0
_rpos 0,DY 
_rpos DX,DY 
.byte 2*BLOCK_WIDTH 
; T in upside position 
T0: 
_rpos 0,0 
_rpos DX,0 
_rpos 2*DX,0 
_rpos DX,DY
.byte 3*BLOCK_WIDTH  
; T 90deg. right 
T1: 
_rpos DX,0 
_rpos 0,DY 
_rpos DX,DY 
_rpos DX,2*DY 
.byte 2*BLOCK_WIDTH
; T upside down 
T2: 
_rpos DX,0 
_rpos 0,DY 
_rpos DX,DY 
_rpos 2*DX,DY 
.byte 3*BLOCK_WIDTH 
; T 90deg. left 
T3: 
_rpos 0,0 
_rpos 0,DY 
_rpos DX,DY 
_rpos 0,2*DY
.byte 2*BLOCK_WIDTH  
; L upside 
L0:
_rpos 0,0 
_rpos 0,DY 
_rpos 0,2*DY 
_rpos DX,2*DY
.byte 2*BLOCK_WIDTH  
; L 90deg. right 
L1:
_rpos 0,0 
_rpos DX,0 
_rpos 2*DX,0 
_rpos 0,DY
.byte 3*BLOCK_WIDTH 
; L upside down 
L2:
_rpos 0,0
_rpos DX,0 
_rpos DX,DY 
_rpos DX,2*DY
.byte 2*BLOCK_WIDTH  
; L 90deg. LEFT  
L3:
_rpos 2*DX,0
_rpos 0,DY 
_rpos DX,DY 
_rpos 2*DX,DY
.byte 3*BLOCK_WIDTH  
; J upside position 
J0: 
_rpos DX,0
_rpos DX,DY 
_rpos 0,2*DY 
_rpos DX,2*DY
.byte 2*BLOCK_WIDTH  
; J 90deg. right 
J1:
_rpos 0,0 
_rpos 0,DY 
_rpos DX,DY 
_rpos 2*DX,DY
.byte 3*BLOCK_WIDTH  
; J upside down 
J2:
_rpos 0,0 
_rpos DX,0
_rpos 0,DY
_rpos 0,2*DY
.byte 2*BLOCK_WIDTH  
; J 90deg left 
J3:
_rpos 0,0
_rpos DX,0 
_rpos 2*DX,0 
_rpos 2*DX,DY
.byte 3*BLOCK_WIDTH   
; Z upside 
Z0:
_rpos 0,0 
_rpos DX,0 
_rpos DX,DY 
_rpos 2*DX,DY  
.byte 3*BLOCK_WIDTH 
; Z 90deg. rotation 
Z1:
_rpos DX,0 
_rpos 0,DY 
_rpos DX,DY 
_rpos 0,2*DY
.byte 2*BLOCK_WIDTH  
; S upside 
S0:
_rpos DX,0
_rpos 2*DX,0
_rpos 0,DY 
_rpos DX,DY
.byte 3*BLOCK_WIDTH  
; S 90deg. rotation 
S1:
_rpos 0,0 
_rpos 0,DY 
_rpos DX,DY 
_rpos DX,2*DY 
.byte 2*BLOCK_WIDTH 

; list of tetraminos in all rotation
tetra_all:  
I_TETRA: .word I0,I1,I0,I1 
SQR_TETRA: .word SQR,SQR,SQR,SQR 
T_TETRA: .word T0,T1,T2,T3 
L_TETRA: .word L0,L1,L2,L3 
J_TETRA: .word J0,J1,J2,J3 
S_TETRA: .word S0,S1,S0,S1 
Z_TETRA: .word Z0,Z1,Z0,Z1 

;-------------------------
; theme tune 
; Russian folk song 
;-------------------------
korobeniki:
    _note MI4,HALF+QUARTER
    _note SOLD4,QUARTER
    _note SI4,HALF 
    _note SOL4,QUARTER
    _note MI4,QUARTER 

    _note LA4,HALF+QUARTER 
    _note DOD5,QUARTER 
    _note MI5,HALF 
    _note RE5,QUARTER 
    _note DO5,QUARTER 
    
    _note SI4,HALF+QUARTER 
    _note DO5,QUARTER 
    _note RE5,HALF 
    _note MI5,HALF 

    _note DO5,HALF 
    _note LA4, HALF 
    _note LA4, WHOLE 

    _note FA5, HALF+QUARTER 
    _note SOL5, QUARTER 
    _note LA5, HALF 
    _note SOL5, QUARTER 
    _note FA5, QUARTER 

    _note MI5, HALF+QUARTER 
    _note FA5, QUARTER 
    _note MI5, HALF 
    _note RE5, QUARTER
    _note DO5, QUARTER 

    _note SI4, HALF+QUARTER 
    _note DO5, QUARTER 
    _note RE5, HALF 
    _note MI5, HALF 

    _note DO5, HALF 
    _note LA4, HALF 
    _note LA4, WHOLE 

    _note 0,0

;-------------------------
; draw tetramino 
; at each block check 
; for collision. 
; if collision stop drawing 
; return collision flag   
; input:
;    X  position {xl,xh}
;    Y  tetra pointer 
; output:
;    A   0 -> no collision 
;        -1 -> collision 
;-------------------------
    TPOS=1 ; tetramino top-left position  
    TLIST=TPOS+2 ; blocks list pointer 
    BCNT=TLIST+2 ; block counter 
    COLLISION=BCNT+1
    VAR_SIZE=COLLISION 
draw_tetra:
    push #0 ;collision flag 
    push #4 ; block counter 
    pushw y  ;block list pointer 
    pushw x  ; top-left position 
1$: ldw x,y
    ldw x,(x)
    addw x,(TPOS,sp)
    ldw y,#TBLOCK 
    ld a,#DY 
    call put_sprite
    jreq 2$ 
    ld a,#-1
    ld (COLLISION,sp),a 
2$: 
    ldw y,(TLIST,sp)
    addw y,#2 
    ldw (TLIST,sp),y 
    dec (BCNT,sp)
    jrne 1$ 
9$:
    ld a,(COLLISION,sp)
    _drop VAR_SIZE 
    ret 

;-------------------------------
; get tetramino 
; sprite address 
; input:
;     A  tetra index {0..7}
;     XL tetra rotation {0..3}
; output:
;    Y   *tetramino 
;------------------------------
get_tetra_sprite:
; addr=tetra_all[8*A+2*XL] 
    sll a 
    sll a 
    sll a 
    clrw y 
    ld yl,a 
    addw y,#tetra_all 
    sllw x 
    pushw x 
    addw y,(1,sp)
    ldw y,(y)
    _drop 2 
    ret 

;-------------------
; display lines and 
; scores 
;-------------------
display_fall_score:
    mov cx,#7 
    _clrz cy 
    ldw x,lines_dropped 
    call put_uint16
    mov cx,#7 
    mov cy,#2 
    ldw x,fall_score
    call put_uint16 
    ret

;-------------------------
; initialize game 
;-------------------------
LINES_STR: .asciz "LINES:\r\rSCORE:"
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

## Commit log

2023-12-02 Dessin du circuit
2023-12-03 Ajout de alt_func.asm
2023-12-03 Déboger tvout.asm et ajout de fonctions dans display.asm
2023-12-04 Ajout de font_small_hex.asm
2023-12-04 suppression de monitor.asm
2023-12-04 Ajout de des sous-routines *crlf*,*cursor_right*,*scrollup* et *put_uint16*.
2023-12-04 Ajout de put_sprite
2023-12-09 réécriture de tv_putc, gain de vitesse 6x
2023-12-10 Ajout de la routine read_keypad
2023-12-10 modification schématique
    [ntsc_tuto.kicad_pcb, ntsc_tuto.kicad_sch]
2023-12-11 retravaillé certains caractères de la police font_6x8.asm
2023-12-13 Travail sur jeu snake.asm mécanique de déplacement du serpent ok lecture du keypad avec antirebond complété
2023-12-15 Complété et débogué mécanique des collisions
    [hardware_init.asm]
2023-12-22 assemblage nouveau circuit et tests préléminaires
    [ntsc_tuto.kicad_pcb, ntsc_tuto.kicad_sch, stm8s207k8.kicad_sch]
2023-12-23 Modification circuit vidéo et swap bouton A et audio out
    [ntsc_tuto.kicad_sch, stm8-gamepad.kicad_pcb, stm8-gamepad.kicad_sch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]
2023-12-25 Ajout de fonctions scroll dans display.asm
2023-12-26 Version NUCLEO-8S207K8 créé
    [nucleo-8s207k8.kicad_sch, stm8-gamepad.kicad_sch]
2023-12-27 modification prototype 1
    [stm8-gamepad.kicad_sch]
2023-12-27 modification delais TIMER4
2023-12-28 Éliminiation du TIM4 pour générer une interruption de 1 msec afin d'obtenir une sortie vidéo plus propre
2023-12-28 réajustement des délais dans snake.asm
2023-12-30 Ajout de la sous-routine tune dans hardware_init.asm
2024-01-04 création de api.md et docs/api.pdf
2024-01-04 Mise à jour readme.md par ajout de photos
2024-01-04 décapitalisé les extensions .JPG en .jpg
2024-01-04 Ajout de docs/stm8_gamepad_nucleo.png
2024-01-10 Ajout de fichier
2024-01-11 nettoyage de conway.asm
2024-01-11 ajout de .gitignore
2024-01-11 restoré fichiers KiCAD supprimé par erreur
    [nucleo-8s207k8.kicad_sch, stm8-gamepad.kicad_pcb, stm8-gamepad.kicad_sch]
2024-01-11 Ajout des routines roll_up et scroll_text
2024-01-12 Ajout de sound.asm et travail sur fall.asm
2024-01-14 Ajout de routine again dans app.asm et travail sur cadena.asm ajout routine get_digit modifié plusieurs routines
2024-01-14 Ajout de cadena.asm au git
2024-01-18 Correction mineure à la routine *again* dans le fichier [app.asm](app.asm). Version V1.2R1 production d'un vidéo de démonstration du jeu CADENA
2024-01-18 Mise à jour du numéro de version dans le fichier config.inc
2024-01-23 ajout de get_pixel et put_pixel dans display.asm
2024-01-24 Modification de conway pour ajouter RANDOM FILL
2024-01-25 correction mineure à la routine rectangle
2024-01-29 Ajout de la routine graphique cercle
2024-02-16 Modification matérielle cristal de 16Mhz remplacé par 24Mhz. Amélioration du rapport largeur/hauteur de l'image maintenant proche de l'utnité
    [nucleo-8s207k8.kicad_sch, stm8-gamepad.kicad_sch]
